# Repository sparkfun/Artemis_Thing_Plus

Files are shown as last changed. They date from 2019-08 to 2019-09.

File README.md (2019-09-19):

SparkFun Artemis Thing Plus
========================================

SparkFun Artemis Thing Plus

[*SparkFun Artemis Thing Plus (15574)*](https://www.sparkfun.com/products/15574)

If you are looking for a board that (almost) does it all, look no further! The SparkFun Artemis Thing Plus takes our popular Thing Plus footprint and adds in the powerful Artemis module for ultimate functionality. Fully compatible with SparkFun's Arduino core, the modern USB-C connector makes it easy to program under the Arduino IDE but for more advanced users who prefer to use the power and speed of professional tools, we've also exposed the JTAG connector. To make the Thing Plus even easier to use, we've moved a few pins around to make the board Feather compatible and it utilizes our handy Qwiic Connect System which means no soldering or shields are required to connect it to the rest of your system!

With 1MB flash and 384k RAM you'll have plenty of room for your sketches. The on-board Artemis module runs at 48MHz with a 96MHz turbo mode available and with Bluetooth to boot! We've added a digital MEMS microphone for folks wanting to experiment with always-on voice commands with TensorFlow and machine learning. The addition of the Qwiic connector opens up plug-and-play I<sup>2</sup>C functionality with our wide array of Qwiic boards. 

With so much functionality, the SparkFun Artemis Thing Plus is an ideal choice for your Internet of Things project. We've even made it Feather-compatible so you can take advantage of a shield option in case you didn't want to use our Qwiic Connect System! If you need more Apollo3 functionality or a more concise form factor, check out our Artemis ATP or Artemis Nano.

Repository Contents
-------------------

* **/Hardware** - Eagle design files (.brd, .sch)

Documentation
--------------
* **[Hookup Guide](https://learn.sparkfun.com/tutorials/hookup-guide-for-the-sparkfun-artemis-thing-plus)** - Basic hookup guide for the Artemis Thing Plus.
* **[Artemis Development with Arduino](https://learn.sparkfun.com/tutorials/artemis-development-with-arduino)**
* **[Ambiq Apollo3 SDK SetUp](https://learn.sparkfun.com/tutorials/using-sparkfun-edge-board-with-ambiq-apollo3-sdk)**
* **[Designing with the SparkFun Artemis](https://learn.sparkfun.com/tutorials/designing-with-the-sparkfun-artemis)**
* **[CH340E USB to serial IC Drivers](https://www.sparkfun.com/ch340)**
* **[SparkFun Fritzing repo](https://github.com/sparkfun/Fritzing_Parts)** - Fritzing diagrams for SparkFun products.

License Information
-------------------

This product is _**open source**_! 

Please review the LICENSE.md file for license information. 

If you have any questions or concerns on licensing, please contact technical support on our [SparkFun forums](https://forum.sparkfun.com/viewforum.php?f=152).

Distributed as-is; no warranty is given.

- Your friends at SparkFun.

_<COLLABORATION CREDIT>_

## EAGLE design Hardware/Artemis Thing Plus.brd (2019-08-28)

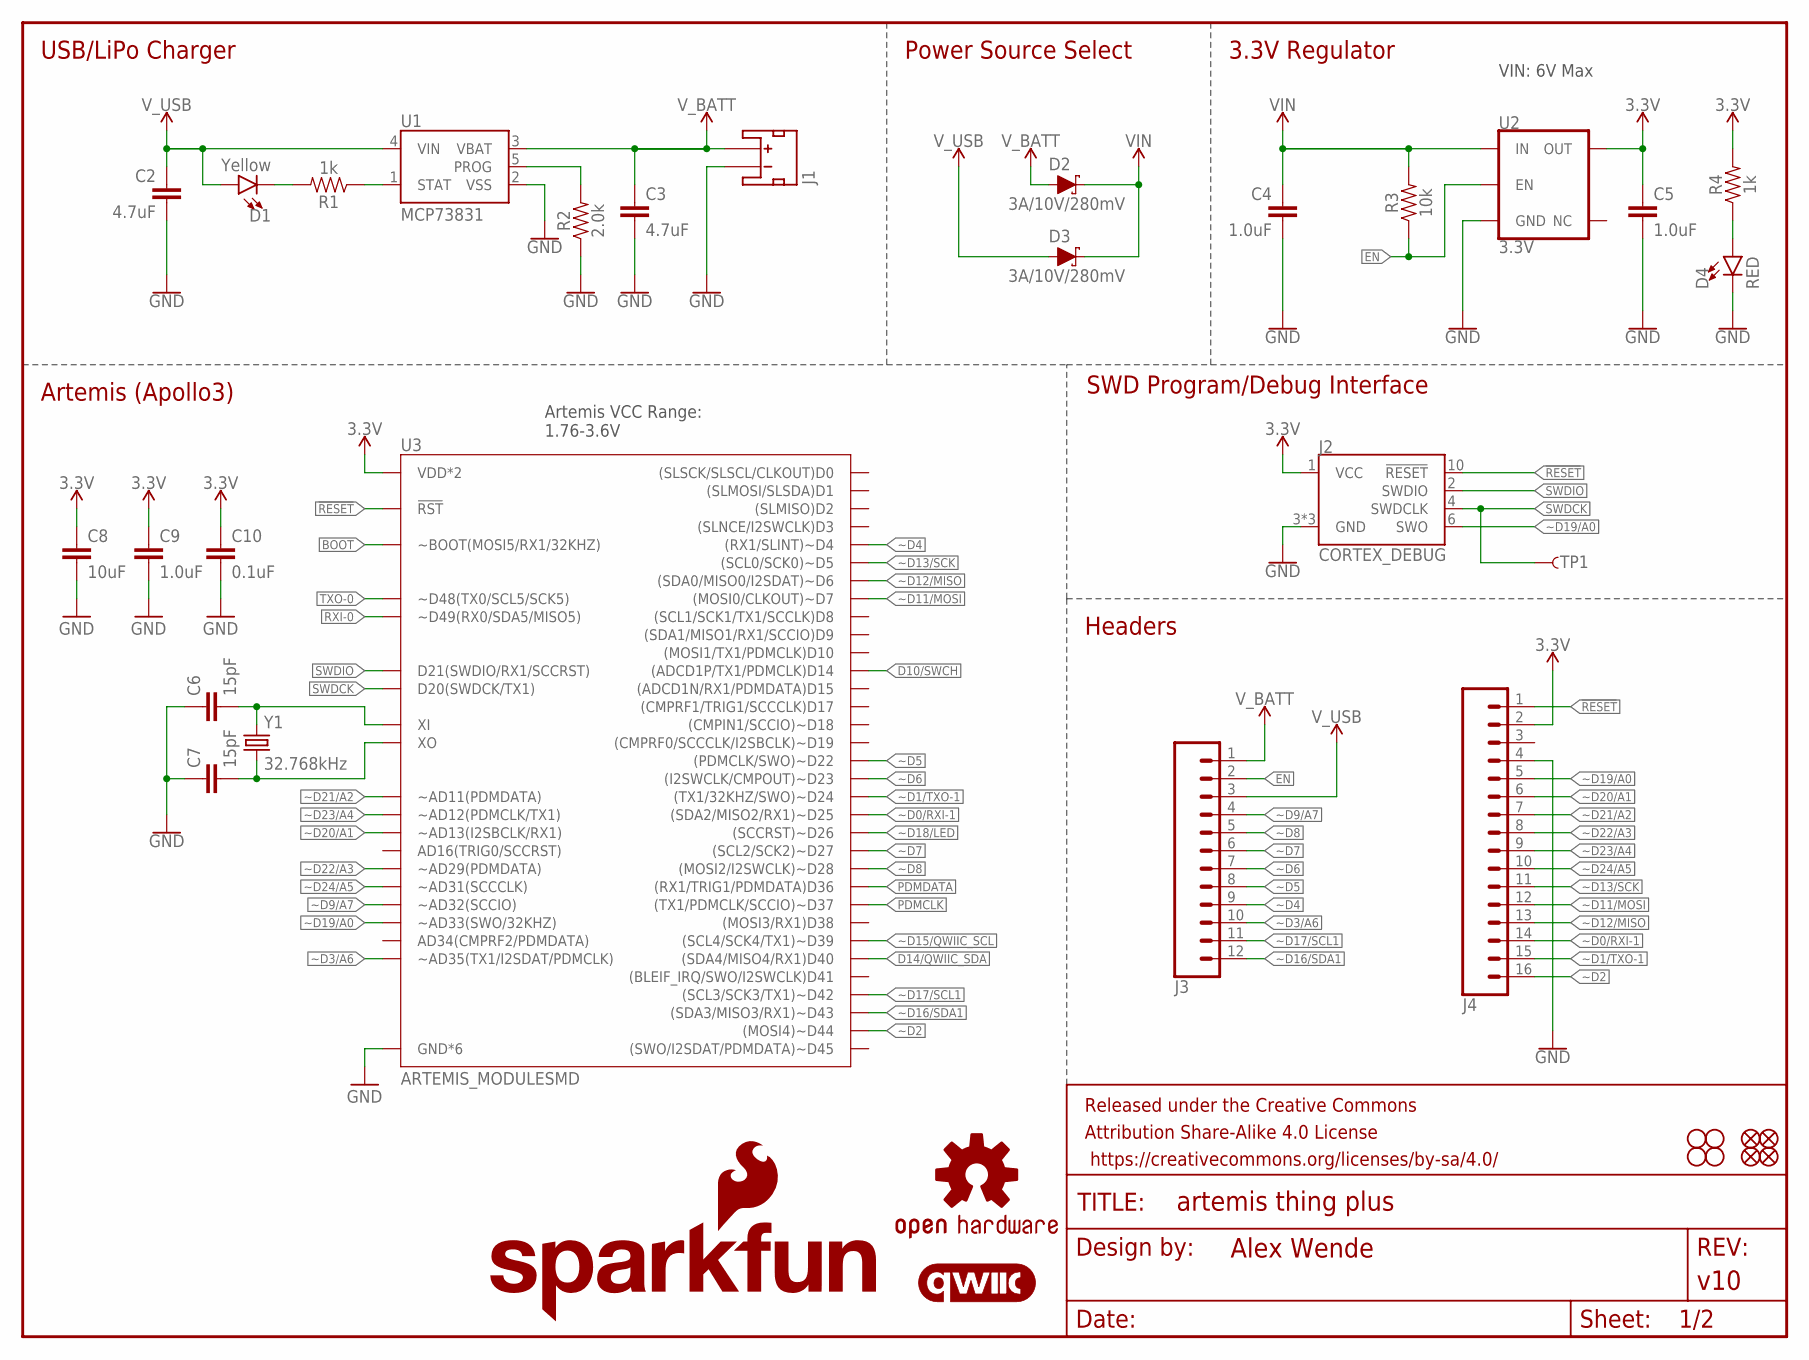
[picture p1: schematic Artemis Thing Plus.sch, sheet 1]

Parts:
C2, C3: 4.7uF; 0603
C4, C5: 1.0uF; 0402-TIGHT
C6, C7: 15pF; 0603
C8: 10uF; 0603
C9: 1.0uF; 0603
C10: 0.1uF; 0603
D1: Yellow; LED-0603
D2, D3: 3A/10V/280mV; SOD-323
D4: RED; LED-0603
FD1, FD2, FD3, FD4: FIDUCIALUFIDUCIAL; FIDUCIAL-MICRO
FRAME1: FRAME-LETTER; CREATIVE_COMMONS
H1, H2, H3, H4: STAND-OFF
J1: JST_2MM_MALE; JST-2-SMD
J2: CORTEX_DEBUG; 2X5-PTH-1.27MM-NO_SILK
J3: CONN_12SM_SQ_NO_SILK; 1X12_SM_SQ_NOSILK
J4: CONN_161X16_SM_SQ_NOSILK; 1X16_SM_SQ_NOSILK
LOGO1: OSHW-LOGOS; OSHW-LOGO-S
LOGO2: QWIIC_LOGO_5MM; QWIIC_5MM
LOGO3: SFE_LOGO_NAME_FLAME.1_INCH; SFE_LOGO_NAME_FLAME_.1
R1, R4: 1k; 0603
R2: 2.0k; 0603
R3: 10k; 0603
TP1: TEST-POINTTP_15TH_THRU; TP_15TH
U1: MCP73831; SOT23-5
U2: 3.3V; SOT23-5
U3: ARTEMIS_MODULESMD; ARTEMIS_FP
Y1: 32.768kHz; CRYSTAL-SMD-3.2X1.5MM

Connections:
3.3V: C5.1, C8.1, C9.1, C10.1, J2.1 (VCC), J4.2, R4.2, U2.5 (OUT), U3.VDD@36 (VDD*2), U3.VDD@37 (VDD*2); also elsewhere on the board
!RESET: J2.10 (!RESET), J4.1, U3.~RST (!RST); also elsewhere on the board
BOOT: U3.BOOT (~BOOT(MOSI5/RX1/32KHZ)); also elsewhere on the board
D10/SWCH: U3.D14 ((ADCD1P/TX1/PDMCLK)D14); also elsewhere on the board
D14/QWIIC_SDA: U3.D40 ((SDA4/MISO4/RX1)D40); also elsewhere on the board
EN: J3.2, R3.1, U2.3 (EN)
GND: C2.2, C3.2, C4.2, C5.2, C6.1, C7.1, C8.2, C9.2, C10.2, D4.C, J1.1 (-), J2.3 (GND), J2.5 (GND), J2.9 (GND), J4.4, R2.1, U1.2 (VSS), U2.2 (GND), U3.GND@1 (GND*6), U3.GND@22 (GND*6), U3.GND@38 (GND*6), U3.GND@39 (GND*6), U3.GND@47 (GND*6), U3.GND@59 (GND*6); also elsewhere on the board
unnamed: R2.2, U1.5 (PROG)
unnamed: C7.2, U3.XO, Y1.P$2 (2)
unnamed: D1.C, R1.2
unnamed: R1.1, U1.1 (STAT)
unnamed: C6.2, U3.XI, Y1.P$1 (1)
unnamed: D4.A, R4.1
PDMCLK: U3.~D37 ((TX1/PDMCLK/SCCIO)~D37); also elsewhere on the board
PDMDATA: U3.D36 ((RX1/TRIG1/PDMDATA)D36); also elsewhere on the board
RXI-0: U3.RXI-0 (~D49(RX0/SDA5/MISO5)); also elsewhere on the board
SWDCK: J2.4 (SWDCLK), TP1.P$1, U3.SWDCK (D20(SWDCK/TX1))
SWDIO: J2.2 (SWDIO), U3.SWDIO (D21(SWDIO/RX1/SCCRST))
TXO-0: U3.TXO-0 (~D48(TX0/SCL5/SCK5)); also elsewhere on the board
VIN: C4.1, D2.C, D3.C, R3.2, U2.1 (IN)
V_BATT: C3.1, D2.A, J1.2 (+), J3.1, U1.3 (VBAT)
V_USB: C2.1, D1.A, D3.A, J3.3, U1.4 (VIN); also elsewhere on the board
~D0/RXI-1: J4.14, U3.~D25 ((SDA2/MISO2/RX1)~D25)
~D1/TXO-1: J4.15, U3.~D24 ((TX1/32KHZ/SWO)~D24)
~D2: J4.16, U3.~D44 ((MOSI4)~D44)
~D3/A6: J3.10, U3.~AD35 (~AD35(TX1/I2SDAT/PDMCLK))
~D4: J3.9, U3.~D4 ((RX1/SLINT)~D4)
~D5: J3.8, U3.~D22 ((PDMCLK/SWO)~D22)
~D6: J3.7, U3.~D23 ((I2SWCLK/CMPOUT)~D23)
~D7: J3.6, U3.~D27 ((SCL2/SCK2)~D27)
~D8: J3.5, U3.~D28 ((MOSI2/I2SWCLK)~D28)
~D9/A7: J3.4, U3.~AD32 (~AD32(SCCIO))
~D11/MOSI: J4.12, U3.D7 ((MOSI0/CLKOUT)~D7)
~D12/MISO: J4.13, U3.~D6 ((SDA0/MISO0/I2SDAT)~D6)
~D13/SCK: J4.11, U3.~D5 ((SCL0/SCK0)~D5)
~D15/QWIIC_SCL: U3.~D39 ((SCL4/SCK4/TX1)~D39); also elsewhere on the board
~D16/SDA1: J3.12, U3.~D43 ((SDA3/MISO3/RX1)~D43)
~D17/SCL1: J3.11, U3.~D42 ((SCL3/SCK3/TX1)~D42)
~D18/LED: U3.~D26 ((SCCRST)~D26); also elsewhere on the board
~D19/A0: J2.6 (SWO), J4.5, U3.~AD33/SWO (~AD33(SWO/32KHZ))
~D20/A1: J4.6, U3.~AD13 (~AD13(I2SBCLK/RX1))
~D21/A2: J4.7, U3.~AD11 (~AD11(PDMDATA))
~D22/A3: J4.8, U3.~AD29 (~AD29(PDMDATA))
~D23/A4: J4.9, U3.~AD12 (~AD12(PDMCLK/TX1))
~D24/A5: J4.10, U3.~AD31 (~AD31(SCCCLK))

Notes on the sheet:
SWD Program/Debug Interface
Headers
Artemis (Apollo3)
USB/LiPo Charger
Power Source Select
3.3V Regulator
Artemis VCC Range: 1.76-3.6V
VIN: 6V Max

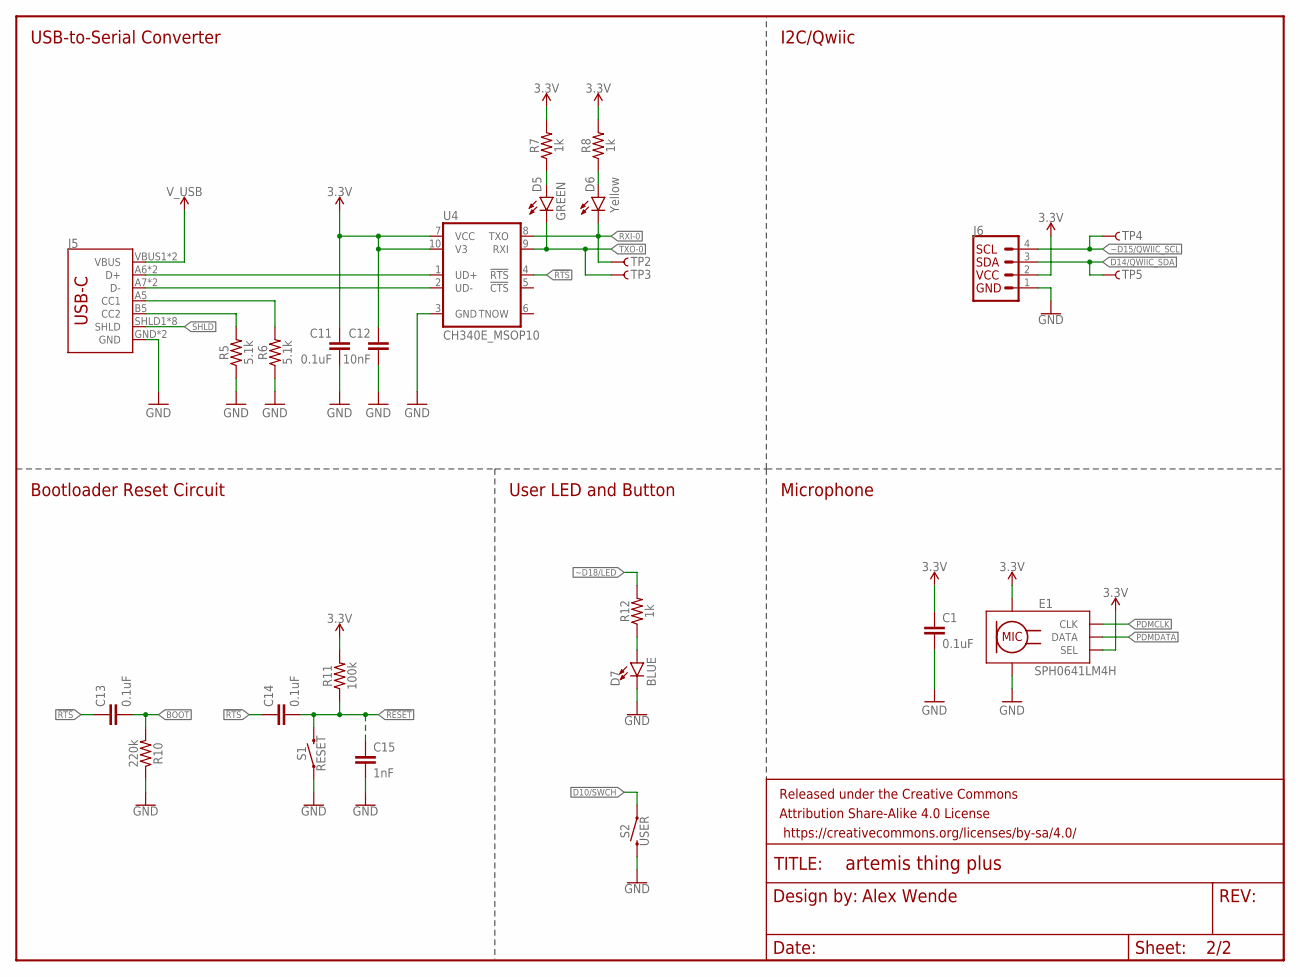
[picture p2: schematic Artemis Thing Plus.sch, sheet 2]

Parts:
C1: 0.1uF; 0402-TIGHT
C11, C13, C14: 0.1uF; 0603
C12: 10nF; 0603
C15: 1nF; 0603
D5: GREEN; LED-0603
D6: Yellow; LED-0603
D7: BLUE; LED-0603
E1: SPH0641LM4H; SPH0641LM4H-1_MICROPHONE
FRAME2: FRAME-LETTERNO_PACKAGE; DUMMY
J5: USB-C; USB-C-16P
J6: QWIIC_CONNECTORJS-1MM; JST04_1MM_RA
R5, R6: 5.1k; 0603
R7, R8, R12: 1k; 0603
R10: 220k; 0603
R11: 100k; 0603
S1: RESET; TACTILE_SWITCH_SMD_4.6X2.8MM
S2: USER; TACTILE_SWITCH_SMD_4.6X2.8MM
TP2, TP3, TP4, TP5: TEST-POINTTP_15TH_THRU; TP_15TH
U4: CH340E_MSOP10; MSOP10

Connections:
3.3V: C1.1, C11.1, C12.1, E1.2 (SEL), E1.5 (VDD), J6.2, R7.2, R8.2, R11.2, U4.7 (VCC), U4.10 (V3); also elsewhere on the board
!RESET: C14.2, C15.1, R11.1, S1.3 (2), S1.4 (2); also elsewhere on the board
!RTS: C13.1, C14.1, U4.4 (!RTS)
BOOT: C13.2, R10.2; also elsewhere on the board
CC1: J5.A5 (CC1), R6.2
CC2: J5.B5 (CC2), R5.2
D10/SWCH: S2.1, S2.2 (1); also elsewhere on the board
D14/QWIIC_SDA: J6.3, TP5.P$1; also elsewhere on the board
D+1: J5.A6 (D+), J5.B6 (D+), U4.1 (UD+)
D-1: J5.A7 (D-), J5.B7 (D-), U4.2 (UD-)
GND: C1.2, C11.2, C12.2, C15.2, D7.C, E1.3 (GND), E1.6 (GND), E1.7 (GND), E1.8 (GND), J5.GND, J5.GND2 (GND), J6.1, R5.1, R6.1, R10.1, S1.1, S1.2 (1), S2.3 (2), S2.4 (2), U4.3 (GND); also elsewhere on the board
unnamed: D5.A, R7.1
unnamed: D7.A, R12.1
unnamed: D6.A, R8.1
PDMCLK: E1.4 (CLK); also elsewhere on the board
PDMDATA: E1.1 (DATA); also elsewhere on the board
RXI-0: D6.C, TP2.P$1, U4.8 (TXO); also elsewhere on the board
SHLD: J5.SHLD1 (SHLD), J5.SHLD2 (SHLD), J5.SHLD3 (SHLD), J5.SHLD4 (SHLD), J5.SHLD5 (SHLD), J5.SHLD6 (SHLD), J5.SHLD7 (SHLD), J5.SHLD8 (SHLD)
TXO-0: D5.C, TP3.P$1, U4.9 (RXI); also elsewhere on the board
V_USB: J5.VBUS1 (VBUS), J5.VBUS2 (VBUS); also elsewhere on the board
~D15/QWIIC_SCL: J6.4, TP4.P$1; also elsewhere on the board
~D18/LED: R12.2; also elsewhere on the board

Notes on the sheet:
Microphone
USB-to-Serial Converter
Bootloader Reset Circuit
User LED and Button
I2C/Qwiic
Alex Wende

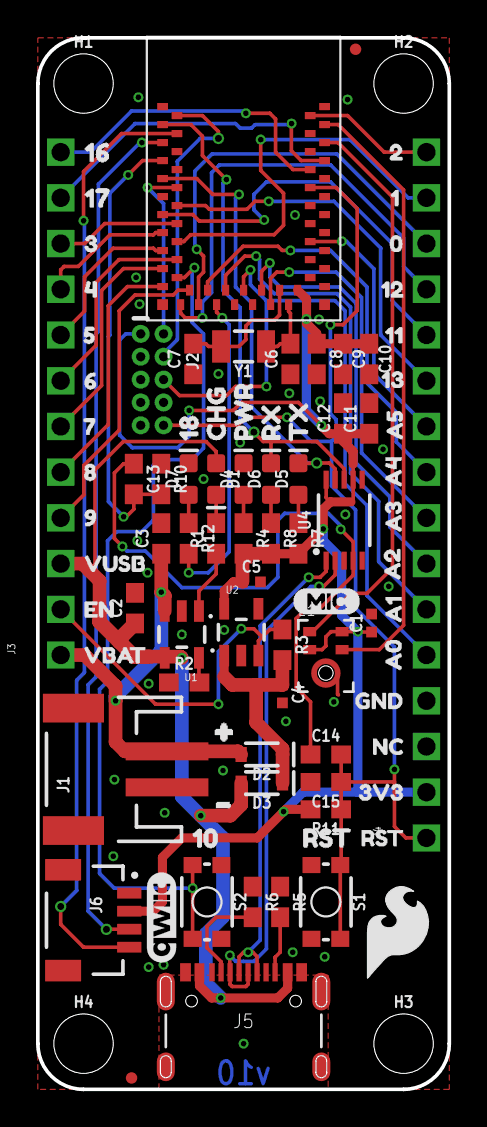
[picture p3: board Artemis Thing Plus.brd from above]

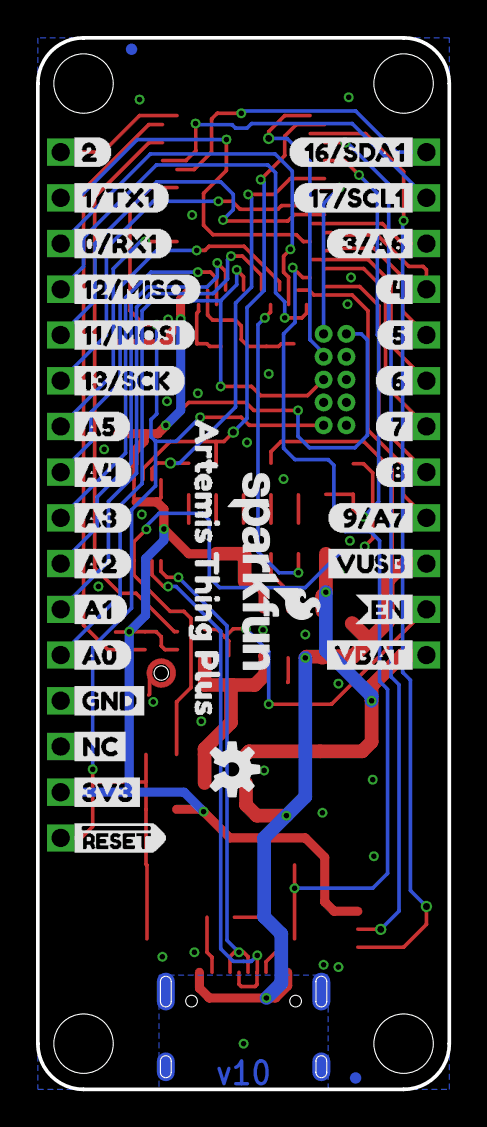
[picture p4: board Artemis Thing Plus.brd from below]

Board: 2 copper layers, 22.9 x 58.4 mm, 133 parts (33 on the bottom side), 54 nets.

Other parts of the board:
U$1: 160
U$2: 171
U$3: 32
U$4: 43
U$5: 54
U$6: 65
U$7: 76
U$8: 87
U$9: 98
U$10: VUSB9
U$11: EN10
U$12: VBAT11
U$13: 227
U$14: 126
U$15: 025
U$16: 1123
U$17: 1224
U$18: 1322
U$19: A521
U$20: A420
U$21: A319
U$22: A218
U$23: A117
U$24: A016
U$25: GND13
U$26: NC12
U$27, U$48: 3V314
U$28: RST15
U$29: 184
U$30: CHG1
U$31: PWR2
U$32: RX3
U$33: TX4
U$34: 20
U$35: 1#TX11
U$36: 0#RX12
U$37: 12#MISO3
U$38: 11#MOSI4
U$39: 13#SCK5
U$40: A56
U$41: A47
U$42: A38
U$43: A29
U$44: A110
U$45: A011
U$46: GND12
U$47: NC13
U$49: #RESET15
U$50: 16#SDA12
U$51: 17#SCL13
U$52: 412
U$53: 513
U$54: 614
U$55: 715
U$56: 816
U$57: 9#A719
U$58: 3#A60
U$59: VUSB25
U$60: EN26
U$61: VBAT27
U$62: 100
U$63: RST1
U$64: ARTEMIS_THING_PLUS0
U$65: SFE_LOGO_FLAME_.2
U$66: MIC0
U$67: #0
U$68: #1

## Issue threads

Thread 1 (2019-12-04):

Expose ITM/SWO pin on SWD/JTAG Connector

oclyke, 2019-12-04:
Will you consider adding a free ITM/SWO pin to the SWD/JTAG connector as is demonstrated on the [Edge](https://cdn.sparkfun.com/assets/2/b/7/4/d/SparkFun_Edge_Schematic.pdf) board? This affords users a different ('pro') way to do debug printing and possibly frees up a UART for another purpose. Inspired by https://github.com/sparkfun/SparkFun_Apollo3_AmbiqSuite_BSPs/issues/19

oclyke, 2019-12-10:
Wait - I jumped the gun. Must have overlooked it but a SWO pin is in fact exposed on the Artemis Thing Plus

Closed 2019-12-10.

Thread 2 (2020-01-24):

Feature request: on-board uSD-slot

idea--list, 2020-01-24:
Hi there,

As the Apollo is an ULP MCU and the Thing Plus has a tiny form factor, many of us will tend to build battery powered solutions that will run several days or maybe even weeks. 99% of long running projects do log sensor data. Radio transmission is not a good idea for battery powered projects, so an on-board uSD-slot would make perfect sense for the thing plus and also for the nano board (right now i can solder an SD breakout but that takes away 6 pins).

Also a way to implement battery metering without additional soldering would be really welcome.

I know these boards were released just few months ago, but if you plan newer revisions please take these into account

oclyke, 2020-01-27:
I think this is an excellent idea! I always love a good uSD slot and the battery monitoring/metering is certainly a big deal for embedded data loggers...

I'm not promising anything but keep an eye out on our products page in the near future for something that might fit the bill!

idea--list, 2020-01-27:
Thanks for the response. I know changing such things are not easy-peasy and also take a while usually. I found a [push-push uSD socket in your store](https://www.sparkfun.com/products/127), that costs under $4. I would not mind paying even $35 for an artemis thing plus with that on board out of the box. :wink:

Let me focus your attention on some further useful considerations:
I have this board right now, as the vendor does not update the SW-stack it got almost unusable as mbed-os evolves...

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
Notice the empty golden patch in top center. Advanced makers can solder a QSPI flash chip there to expand the memory significantly. The patch itself costs only some cents to implement.

Imagine someone would like to log weather data continuously for several weeks/months (or record some analog signal) from a battery out in the field far away from any computer or laptop. For that case even the SD is suboptimal (as there is an MCU built into the SD card that consumes ~100mA when writing so the project would not work long on batteries). Offering a QSPI patch and support for 256MB or above QSPI chips would open up whole new dimensions for the Apollo MCU! :rocket:

Also note how the SD-slot is placed. If you ever release any boards with an on-board SD socket, please do not place it like in my picture. I mean that might be okay until you sit in your lab next to your computer, but again if you have a real battery powered project, then the device is not installed in your lab and the next computer might be miles away. Chances are about 100% the project would have some enclosure in such a case. Any casing is at least 2-3mm thick... now if you would place the socket as you can see in the picture, than you just will not be able to remove/change the card as it does not extend beyond the casing. The push-pull socket makes that even more problematic. So the user would end up with tons of logged data they just can not access despite a slot for the card has been planned&printed on the casing... and you just do not want your makers feel :tired_face:

If you happen to have a computer and an USB cable at your hands, you could try to access those data via USB (exactly that functionality is not supported anymore for my board causing me looking for alternatives). In that case however by placing the socket more centrally, the user would not need to bother about implementing a hole on the casing...:wink:

So to sum it up: place a push-push SD socket as close to the edge of the board as possible. That way the maker has the choice: if they want removable SD-cards, they could really remove that even if the project has a protective enclosure. Would they prefer a dust-proof  design, they just would plan a bit longer casing to cover the SD card completely, as a compromise they could access the data via USB only and not by changing the card. For more advanced users who really want the longest battery life possible, you should also deliver the board with a QSPI memory of great capacity or if you want cut down manufacturing costs, then implement only an empty QSPI patch for that purpose.

Hope this somewhat long comment inspires your mind and helps you avoid pitfalls an other vendor could not do.

oclyke, 2020-01-28:
Thanks @idea--list! These are certainly great things to keep in mind. We love hearing feedback from customers - especially when you share details about your use cases.

I will leave this issue open for more people to find when designing new boards.

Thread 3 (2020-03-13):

How to start with mBed-os right now

idea--list, 2020-03-13:
Hi there,

I know development is still under progress, but i would really like to start&see what we have today.
Tried to download [this](https://github.com/sparkfun/mbed-os-ambiq-apollo3/tree/ambiq-apollo3-ble2) "ambiq-apollo3-ble2" branch from your "mbed-os-ambiq-apollo3" repo and copy it's content into the mbed-os folder of the project, but it did not work that way.

So my question is how to start programming the Artemis Thing Plus board in mBed-os with mBed Studio at this time?

oclyke, 2020-03-20:
Hi @idea--list - Just wanted to let you know that I'm working on getting you some answers. I am trying to set up Mbed Studio to use our custom targets right now but have run into a little difficulty.

For example I seem to have to manually replace just the 'targets' directory in order to show them in the target dropdown. Once I do that we run into further errors - e.g. that our targets don't support the ARMC6 toolchain (our development has been focused on GCC_ARM because it is free - I am looking into the possibility of using ARMC6 across all our dev environments to decide whether to invest time in supporting it)

Have you tried using the mbed cli? It can be a little finicky to get set up however once you do it seems to work well.

P.s. in order to support you and other customers with similar wishes I created a new branch based on the ble2 branch that adds target support for all of our Apollo3 boards. That's here: [ambiq-apollo3_add-sf-boards](https://github.com/sparkfun/mbed-os-ambiq-apollo3/tree/ambiq-apollo3_add-sf-boards)

Once you get the cli working you should be able to compile for various targets like this:
```mbed compile --target $TARGET --toolchain GCC_ARM```
where ```$TARGET``` is one of the following:
* SparkFun_Artemis_Module
* SparkFun_RedBoard_Artemis
* SparkFun_RedBoard_Artemis_ATP
* SparkFun_RedBoard_Artemis_Nano
* SparkFun_Artemis_Thing_Plus
* SparkFun_Edge

Please keep in mind these are mostly untested right now - due to covid-19 we just recently transitioned to working from home so many of us at SparkFun have been working on setting up our work environments at home. I will keep you posted on developments.

idea--list, 2020-03-20:
Thanks, that is sounds great! Actually i have experience with the online compiler and Mbed Studio, but after all i will get my hands dirty with the cli. After all for me the only thing that really matters is the ability to program in Mbed.

I think will have to play a bit with cli on my windows based system.

idea--list, 2020-03-21:
I think i got stuck.

Here is what i have done:
- installed mbed-cli with the [windows installer](https://github.com/ARMmbed/mbed-cli-windows-installer/releases/tag/v0.4.10)
- studied the doc of mbed-cli found [here](https://github.com/ARMmbed/mbed-cli/blob/1.8.3/README.md)
- compiled&ran the blinky example to the MAX32630FTHR successfully. So i guess i installed everything properly.

- downloaded the [mbed branch](ambiq-apollo3_add-sf-boards) you suggested and replaced the contents of /mbed-os found in the root of my project folder with your branch

- in powershell i entered the following command: `mbed compile --target SparkFun_Artemis_Thing_Plus --toolchain GCC_ARM  ` Compilation starts, but throws the following error after some seconds: [mbed] ERROR: "C:\Python27\python.exe" returned error.
       Code: 1
       Path: "C:\mbed-cli\mbed-cli\projects\mbed-os-program"
       Command: "C:\Python27\python.exe -u C:\mbed-cli\mbed-cli\projects\mbed-os-program\mbed-os\tools\make.py -t GCC_ARM -m SparkFun_RedBoard_Artemis --source . --build .\BUILD\SPARKFUN_REDBOARD_ARTEMIS\GCC_ARM -v"
       Tip: You could retry the last command with "-v" flag for verbose output

I guess there is something wrong with the pin definitions, but i might be wrong.
I found GCC 6.3.1 on my system so i did not install a newer one, am not sure if that might causing it or not.

Do you have any idea what am i doing wrong?

Here is a screenshot:
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

idea--list, 2020-03-21:
Made some progress on trial&error basis.
Modified in the root directory of my project i deleted the `mbed-os` folder as that contains the latest official release which is currently 5.15.1. Of course that version has not got any clue about the Artemis boards. So i downloaded manually and extracted the ambiq-apollo3_add-sf-boards branch you suggested under project root/mbed-os.

On compilation i got errors telling me about duplicate definitions. So i navigated to project root/mbed-os/targets/TARGET_Apollo3/TARGET_AMA3B1KK/  and there i deleted `TARGET_SparkFun_Edge` directory. In the `TARGET_SparkFun_Artemis_Module` directory i kept only `TARGET_SparkFun_Artemis_Thing_Plus` and removed all other directories there.

Now the compilation is successfully completed in powershell, i also can find the .bin file in the BUILD directory.

I found your [Artemis firmware uploader tool](https://github.com/sparkfun/Artemis-Firmware-Upload-GUI) that recognizes the COM port as expected, also the RX LED blinks on the Artemis Thing Plus while i am uploading the .bin file... but ultimately after uploading the firmware, nothing happens (actually it is a really basic blink example and i also try to output "hello world" with the Serial API of mBed). No matter if i press the RST button or power cycle the board.

I guess i miss something but i can not go further than this, any help is highly appreciated!

idea--list, 2020-03-22:
In [this](https://forum.sparkfun.com/viewtopic.php?f=170&t=51685&p=211358&hilit=segger#p211358) forum thread i found a description for setting up Segger for the Artemis boards. Robin_hodgson tells there is a special bootloader on all the Artemis boards so that the program code should begin at 0x00010000. For this to happen in mBed we need to place a file called `mbed_rtx.h` within the `TARGET_Ambiq_Micro` directory. The file should contain:
```
/* mbed Microcontroller Library
 * Copyright (c) 2016 ARM Limited
 *
 * Licensed under the Apache License, Version 2.0 (the "License");
 * you may not use this file except in compliance with the License.
 * You may obtain a copy of the License at
 *
 *     http://www.apache.org/licenses/LICENSE-2.0
 *
 * Unless required by applicable law or agreed to in writing, software
 * distributed under the License is distributed on an "AS IS" BASIS,
 * WITHOUT WARRANTIES OR CONDITIONS OF ANY KIND, either express or implied.
 * See the License for the specific language governing permissions and
 * limitations under the License.
 */

#ifndef MBED_MBED_RTX_H
#define MBED_MBED_RTX_H

#if defined(TARGET_SparkFun_Artemis_Thing_Plus)

#ifndef INITIAL_SP
#define INITIAL_SP              (0x00010000UL)
#endif

#endif

#endif  // MBED_MBED_RTX_H
```

This time i cared only about the Thing Plus board. The code compiles but still does not execute on the board. However i noticed that the color of chart in the `project_name_map.html` found in the BUILD directory turns to ivory. Without this file in place the chart is red, so i guess mbed cli somehow senses a difference.

oclyke, 2020-03-23:
@idea--list Excellent work! Sorry I have been away over the weekend.

You must be right about the duplicate definitions - I will try to reorganize the directory structure so that it works out of the box.

As for why the code is not executing... Here's my suspicion: The linker script used in our mBed project is designed to work with the underlying bootloader - the one that expects code to begin at location 0xC000 in flash. Right now our mBed work is not supported by the GUI uploader because that one expects to find the secondary bootloader that we flash on at the SparkFun factory.

To get you on the same page as us I would suggest that you upload your binaries with the [Ambiq Secure Bootloader](https://github.com/sparkfun/SparkFun_Apollo3_AmbiqSuite_BSPs/blob/bb26f2761df92d3c31d9c8d0200e3385a136764c/common/tools_sfe/ambiq/ambiq_bin2board.py)

Example usage:
```
python3 ambiq_bin2board.py --bin "path\to\your\binary.bin" --load-address-blob 0x20000 --magic-num 0xCB -o "." --version 0x0 --load-address-wired 0xC000 -i 6 --options 0x1 -b 115200 -port "COMX" -r 2 -v
```

That tool will use the underlying bootloader and correctly position the code beginning at 0xC000.

There may also be another bug / issue that we haven't solved yet concerning hte startup process. We've found that you may need to press reset an additional time after bootloading an mBed program.

Keep me informed of your progress! I will get back to this ASAP and I can start making some changes to the branch based on your findings.

(P.s. thanks for your praise of the Artemis GUI Uploader! We're always striving to make it easier to use Artemis. Your help / feedback plays a big part of that process!)

idea--list, 2020-03-24:
Will keep you informed next week. Until then i do not have my board at my hands.
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
idea--list, 2020-07-18:
@oclyke
After successfully programming my Artemis Thing Plus board with mbed-cli i just tried to get things work even with Mbed Studio.

Reason for that is Mbed Studio has built in code hinting, error marking, etc. Here is what i find:
1. One needs to create a "New Program" in Mbed Studio. That way a project folder will be created with an "mbed-os" folder within it containing the latest mbed-os version (currently v6.2). As that version does not have any idea of the Artemis boards yet, one needs to download the ambiq-apollo3-dev branch of mbed-os found [here](https://github.com/sparkfun/mbed-os-ambiq-apollo3/tree/ambiq-apollo3-dev). Then copy the "mbed-os/targets/TARGET_Ambiq_Micro" folder under the proper path of the Mbed Studio project (C:\Users\{USER}\Mbed Programs\mbed-os-example-blinky\mbed-os\targets\      by default on a Win10 system).

2. One also needs to overwrite C:\Users\{USER}\Mbed Programs\mbed-os-example-blinky\mbed-os\targets\targets.json file with the targets.json file that is found in the ambiq-apollo3-dev branch of mbed-os.

Basically you already mentioned these 2 steps on 20th March in your first reply. There you told me the next hurdle is that Mbed Studio relies on the ARM compiler which is not compatible with the Artemis board.

3. [here ](https://os.mbed.com/docs/mbed-studio/current/installing/switching-to-gcc.html)i found how to configure Mbed Studio to use GCC as the compiler.

With these modifications i can write and also compile my code in Mbed Studio, but the code hinting makes some false markings. For example in case of `DigitalOut led(LED1);` it tells me DigitalOut is of unknown type name and i should rather use `mbed::DigitalOut led(LED1);`  (actually both variants run when flashed to the board)

As i do not have JTAG connector soldered on my board i still can not flash the board directly from Mbed Studio (it relies on DAPLink i think) but i still can flash the board using a command line tool and type `python3 C:/AmbiqSuiteSDK/boards_sfe/common/tools_sfe/ambiq/ambiq_bin2board.py --bin "BUILD/SFE_ARTEMIS_THING_PLUS/GCC_ARM/mbed-os-example-blinky.bin" --load-address-blob 0x20000 --magic-num 0xCB -o "." --version 0x0 --load-address-wired 0xC000 -i 6 --options 0x1 -b 115200 -port "COM4" -r 2 -v`

To sum it up at the time of being even the Mbed Studio workflow is shaping up nicely, only the improper code hinting of Mbed Studio in case of the Artemis boards should be ironed out to unveil the full potential of Mbed Studio.

oclyke, 2020-07-29:
Thanks @idea--list this will be very useful! P.s. have you tried the latest improvements to our mbed repo?

Closed 2020-03-27.

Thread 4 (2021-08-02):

Feature request: Use the PCB of hte expLoRaBLE board in future production batches

idea--list, 2021-08-02:
Just noticed the PCB of SparkFun LoRa Thing Plus - expLoRaBLE also offers 3 jumpers (one is for the LED amongst them), but other than that the board schematics seems to be identic to that of SparkFun Thing Plus - Artemis.

Really do not know how many ready made PCB's for the Thing Plus you have on your stock, however would yu ever run out of those it would be great to use the PCB of the explorable board in future production batches of the Thing Plus board. I guess cutting the LED jumper would significantly reduce the power consumption of the Thing Plus board.

Further suggestions in case you are ready to change the board design:
- As far as i can figure out, the Apollo3 MCU has an internal Voltage divider (on VDD*2 pad on the schematic), that is lead to the 3V3 output of the power regulator...which does not make much sense as that should output a steady 3V3 while fed with any voltages the regulator can operate with. This renders battery monitoring impossible with this pad.
- Other analog pins of the board get saturated above 2.0 volts, so again no good for battery monitoring unless one adds a voltage divider (just what we can see on the OpenLog Artemis).
- So adding the same voltage divider or routing the VDD*2 pad to at least 1 analog pin to allow for direct battery monitoring would be welcome.
- Add an on-board SD-slot like on most of your recent boards with any MCUs.

nseidle, 2021-08-03:
Good feedback! Thanks!

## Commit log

2019-07-29 v10
    Initial Commit
    [Artemis Thing Plus.brd, Artemis Thing Plus.sch]
2019-08-05 v10 Update
    Schematic:
    - Change 100k pull-down resistor in bootloader circuit to DNP
    - Replaced diodes with lower forward voltage drop
    - Added second I2C Bus to breakout pins. All broken out pins are now PWM capable
    - Replaced 4.7k LEDs resistors to 1k for all LEDs
    - Added testpoints for Qwiic data lines
    Layout:
    - Removed "~" for PWM pins as all pins now support PWM
    - Increased flame logo
    - Fixed USB traces
    - Labeled microphone
    [Artemis Thing Plus.brd, Artemis Thing Plus.sch]
2019-08-06 v10 design review changes
    [Artemis Thing Plus.brd, Artemis Thing Plus.sch]
2019-08-07 v10 QC fixes
    Added + and - symbols to JST connector
    [Artemis Thing Plus.brd, Artemis Thing Plus.sch]
2019-08-28 Update Artemis Thing Plus.brd
    Adjusted CH340 RTS signal for better ground pour
    [Artemis Thing Plus.brd]

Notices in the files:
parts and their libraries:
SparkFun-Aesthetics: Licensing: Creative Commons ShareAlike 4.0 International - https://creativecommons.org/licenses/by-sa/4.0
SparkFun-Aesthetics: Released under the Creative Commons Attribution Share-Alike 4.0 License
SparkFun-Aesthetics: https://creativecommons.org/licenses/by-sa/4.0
